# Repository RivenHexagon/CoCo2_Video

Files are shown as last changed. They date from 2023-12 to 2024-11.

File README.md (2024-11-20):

# RHCCV - Color Computer 2 S-Video and Composite Mod with Audio 

The ***RHCCV*** is a video mod for the ***Tandy Radio Shack Color Computer 2***. The modification **replaces** the **original** video **module** (the shiny metal box) of the *CoCo2*. It features a **6-pin** or **4-pin** compatible **Mini DIN** connector with **S-Video**, **Composite Video** and **Audio** outputs.

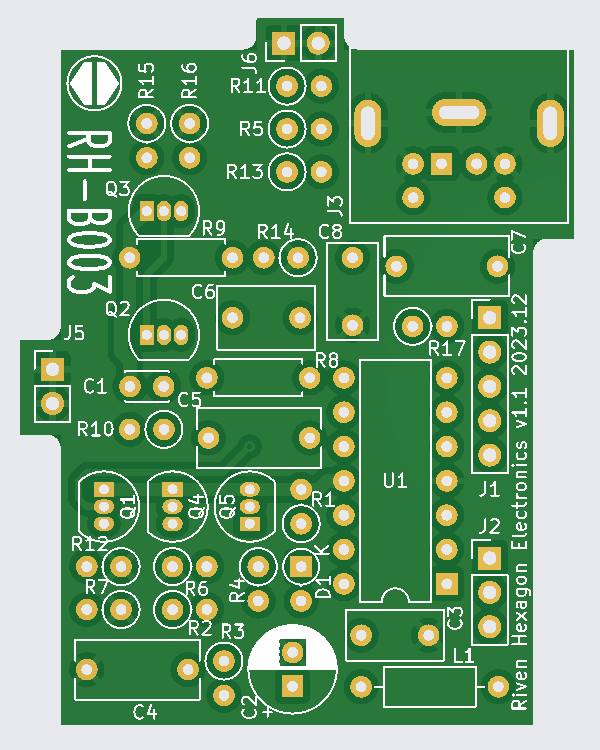
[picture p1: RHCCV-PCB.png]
MarineGEO circle logo


The [/jlcpcb](https://github.com/RivenHexagon/CoCo2_Video/tree/main/jlcpcb) folder contains production-ready files that can be directly uploaded to [jlcpcb.com](https://jlcpcb.com/) for PCB manufacturing.

## Compatibility
The current printed circuit board layout is designed to fit the CoCo2 model with a **horizontally** mounted RF **modulator** case. However, the modification itself would **also** work on earlier CoCo2 versions that use a **vertically** mounted modulator box. The only **differences** are in the **pinout** and the PCB **form factor**. I intend to develop a **revised** PCB **layout** to **fit** the **earlier** form factor, with completion expected by January 2025.
## Assembly and Installation
### 4-pin Mini DIN installed *(S-Video only)*
The **PCB** populated with a **4-pin** Mini DIN connector delivers **S-Video** as the **only** available **output**. The **pinout** is **standard** S-Video, as described [here](https://en.wikipedia.org/wiki/S-Video "S-Video Wikipedia").

### 6-Pin Mini DIN installed *(S-Video, Composite and Audio)*
The **6-pin** connector installed on the **PCB** makes **all** outputs available **simultaneously**. However, this requires a **custom** made **breakout cable** in order to **access** the **signals** individually. A veteran **PS/2** cable can be **modified** but please note that in some cables **not all pins** are **connected**.

The 6-pin Mini DIN connector has the following **pinout**:
* Pin 1: **Audio** out
* Pin 2: **Composite** Video
* Pin 3: **GND**
* Pin 4: **GND**
* Pin 5: **Luma** (Y)
* Pin 6: **Chroma** (C)

The KiCad PCB design uses a custom footprint for *ASSMANN* Mini DIN Connectors:<br>
<https://www.assmann-wsw.com/uploads/datasheets/ASS_1622_CO.pdf>

### Installation
* Desolder the **clamps** of the **metal** box and the **pin headers** of the original video module from the **main board**. (It is recommended to use a **desoldering pump** and **solder wick**)
* Carefully **desolder** the ***MC1372*** from the PCB of the original video module.
* On the RHCCV **PCB**, install a 14-pin **[IC socket](https://www.assmann-wsw.com/uploads/datasheets/ASS_0810_CO.pdf)** for **U1**, rather than soldering the ***MC1372*** directly onto the board.
* Make sure that the **pins** of the *MC1372* are **free of solder** and plug it into the **IC socket** of the RHCCV. Mind the correct **orientation**.
* Populate the remaining components listed in the [Bill of Materials](https://github.com/RivenHexagon/CoCo2_Video/blob/main/TRS-80-VideoMod-BOM.pdf).

The new PCB uses the **same** pin headers as the **original** module and does not require any additional wires to be pulled.

## The Mod
The **design** draws **inspiration** from the research and work of ***[AC's 8-bit Zone](https://youtu.be/tayGsz7Xs3A "ACs 8-bit Zone - YouTube")*** on *YouTube*. The RHCCV mod **integrates** his **S-Video** and **Conmposite Video** circuits into a **single** PCB.

The use of **Mini DIN** connectors in this PCB design provides several **benefits**:
* **Preserves** the **original hardware** (except for desoldering the *MC1372*)
* **Eliminates loose cables** exiting the TRS-80 case
* **No case modification** for extra connectors required

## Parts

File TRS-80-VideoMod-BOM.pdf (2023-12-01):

CoCo2VideoMod

Page 1

Item | Qty Reference(s) Value | LibPart | Footprint
1 | 1 C1 | 100p | Device:C | Capacitor_THT:C_Disc_D3.0mm_W2.0mm_P2.50mm
2 | 1 C2 | 220u | Device:C_Polarized | Capacitor_THT:CP_Radial_D6.3mm_P2.50mm
3 | 2 C3, C8 | 22n | Device:C | Capacitor_THT:C_Rect_L7.0mm_W3.5mm_P5.00mm
4 | 3 C4, C5, C7 | 100n | Device:C | Capacitor_THT:C_Rect_L9.0mm_W4.2mm_P7.50mm_MKT
5 | 1 C6 | 1u | Device:C | Capacitor_THT:C_Rect_L7.0mm_W4.5mm_P5.00mm
6 | 1 D1 | 1N4148 | Device:D | Diode_THT:D_DO-35_SOD27_P2.54mm_Vertical_AnodeUp
7 | 1 J1 | 20261043 Connector_Generic:Conn_01x05 Connector_PinHeader_2.54mm:PinHeader_1x05_P2.54mm_Vertical
8 | 1 J2 | to PCB | Connector_Generic:Conn_01x03 Connector_PinHeader_2.54mm:PinHeader_1x03_P2.54mm_Vertical
9 | 1 J3 | Video | Connector_Generic:Conn_01x07 Custom_Footprints:Connector_Mini-DIN_Female_6Pin_2rows
10 | 1 L1 | 10u | Device:L | Inductor_THT:L_Axial_L6.6mm_D2.7mm_P10.16mm_Horizontal_Vishay_IM-2
11 | 3 Q1, Q3, Q5 | BC547 | Transistor_BJT:BC547 | Package_TO_SOT_THT:TO-92_Inline
12 | 2 Q2, Q4 | BC557 | Transistor_BJT:BC557 | Package_TO_SOT_THT:TO-92_Inline
13 | 2 R1, R15 | 680R | Device:R | Resistor_THT:R_Axial_DIN0207_L6.3mm_D2.5mm_P2.54mm_Vertical
14 | 1 R2 | 5k6 | Device:R | Resistor_THT:R_Axial_DIN0207_L6.3mm_D2.5mm_P2.54mm_Vertical
15 | 2 R3, R4 | 220R | Device:R | Resistor_THT:R_Axial_DIN0207_L6.3mm_D2.5mm_P2.54mm_Vertical
16 | 3 R5, R11, R13 75R | Device:R | Resistor_THT:R_Axial_DIN0207_L6.3mm_D2.5mm_P2.54mm_Vertical
17 | 1 R6 | 3k3 | Device:R | Resistor_THT:R_Axial_DIN0207_L6.3mm_D2.5mm_P2.54mm_Vertical
18 | 3 R7, R12, R16 470R | Device:R | Resistor_THT:R_Axial_DIN0207_L6.3mm_D2.5mm_P2.54mm_Vertical
19 | 1 R8 | 680R | Device:R | Resistor_THT:R_Axial_DIN0207_L6.3mm_D2.5mm_P7.62mm_Horizontal
20 | 1 R9 | 4k7 | Device:R | Resistor_THT:R_Axial_DIN0207_L6.3mm_D2.5mm_P7.62mm_Horizontal
21 | 1 R10 | 330R | Device:R | Resistor_THT:R_Axial_DIN0207_L6.3mm_D2.5mm_P2.54mm_Vertical
22 | 1 R14 | 10k | Device:R | Resistor_THT:R_Axial_DIN0207_L6.3mm_D2.5mm_P2.54mm_Vertical
23 | 1 R17 | 3k9 | Device:R | Resistor_THT:R_Axial_DIN0207_L6.3mm_D2.5mm_P2.54mm_Vertical
24 | 1 U1 | MC1372P TRS-80:MC1372P | Package_DIP:DIP-14_W7.62mm

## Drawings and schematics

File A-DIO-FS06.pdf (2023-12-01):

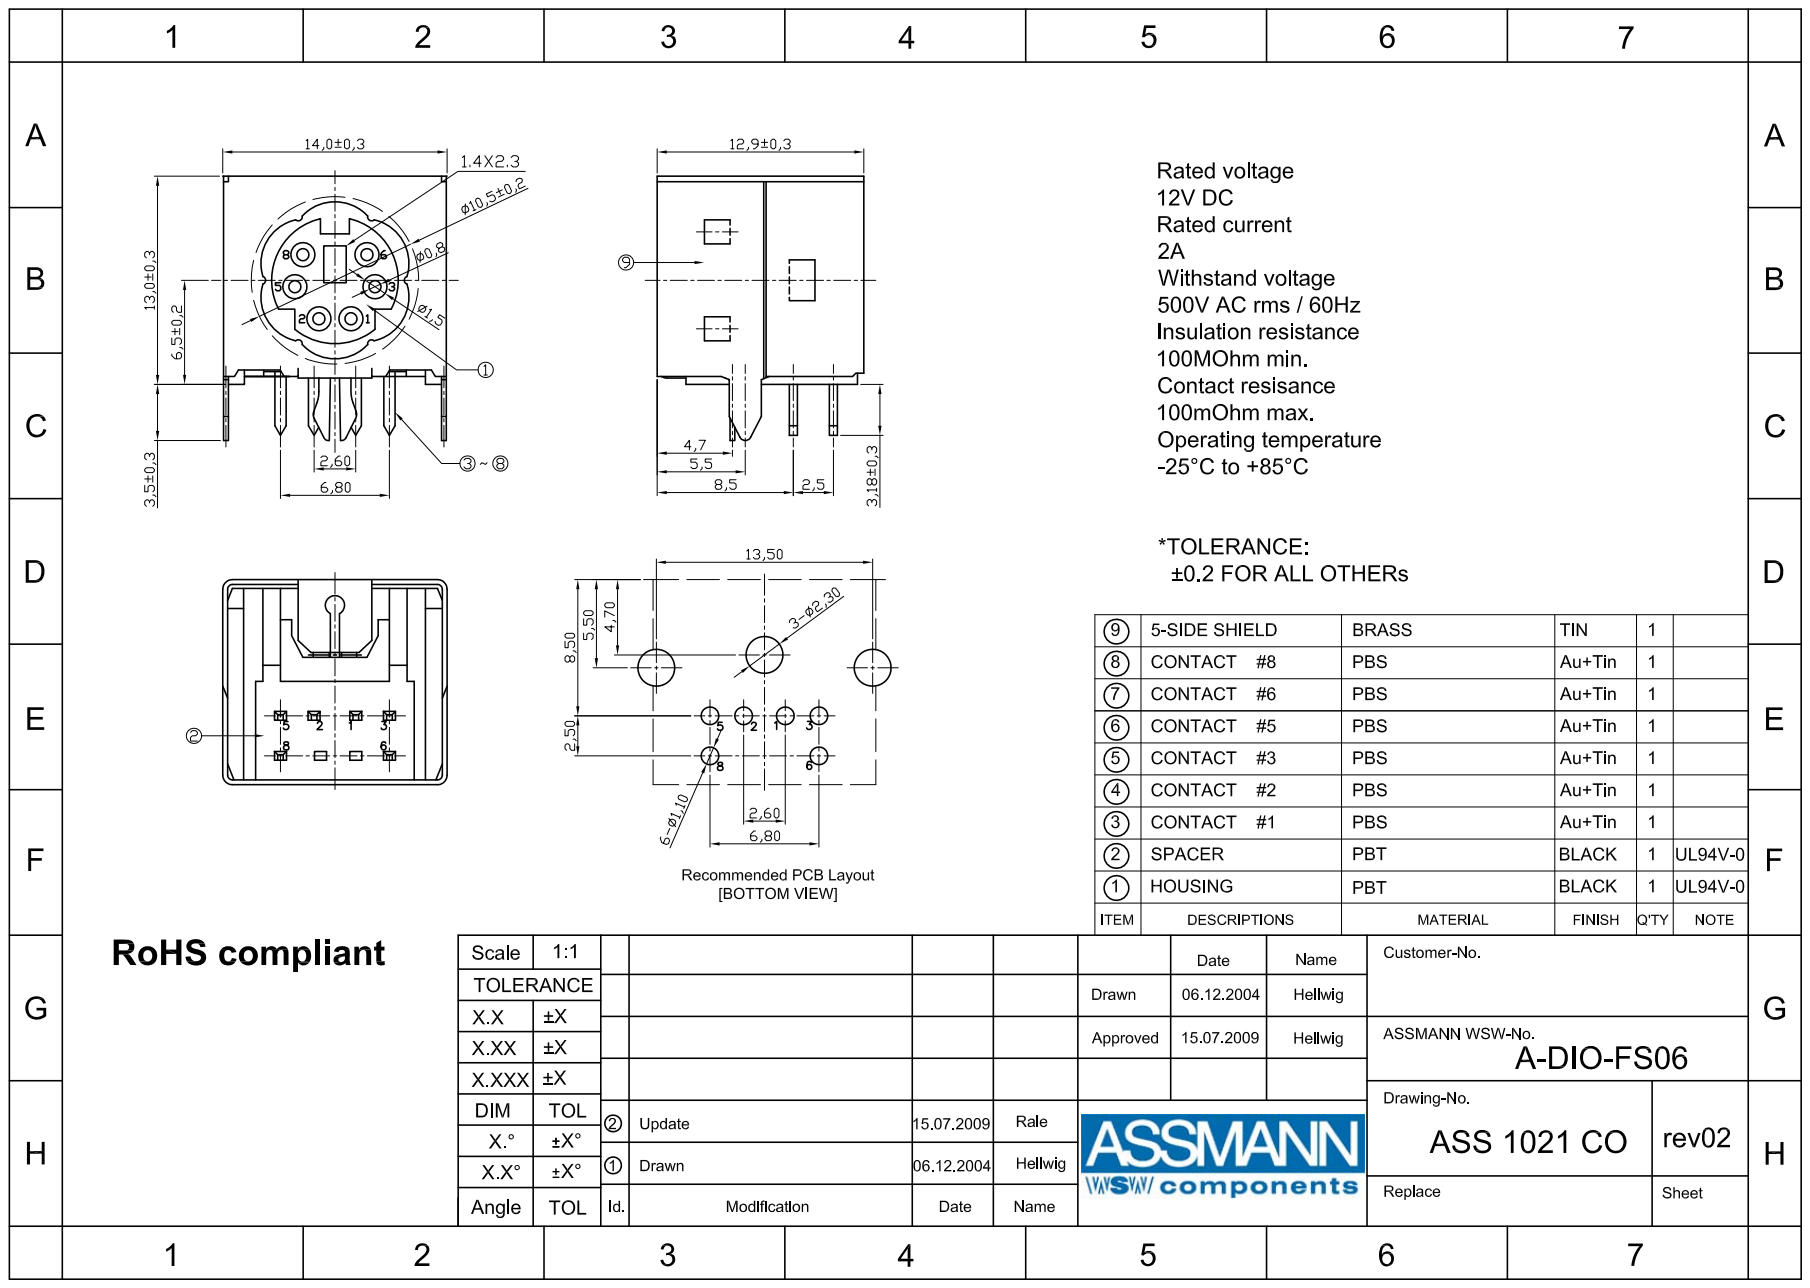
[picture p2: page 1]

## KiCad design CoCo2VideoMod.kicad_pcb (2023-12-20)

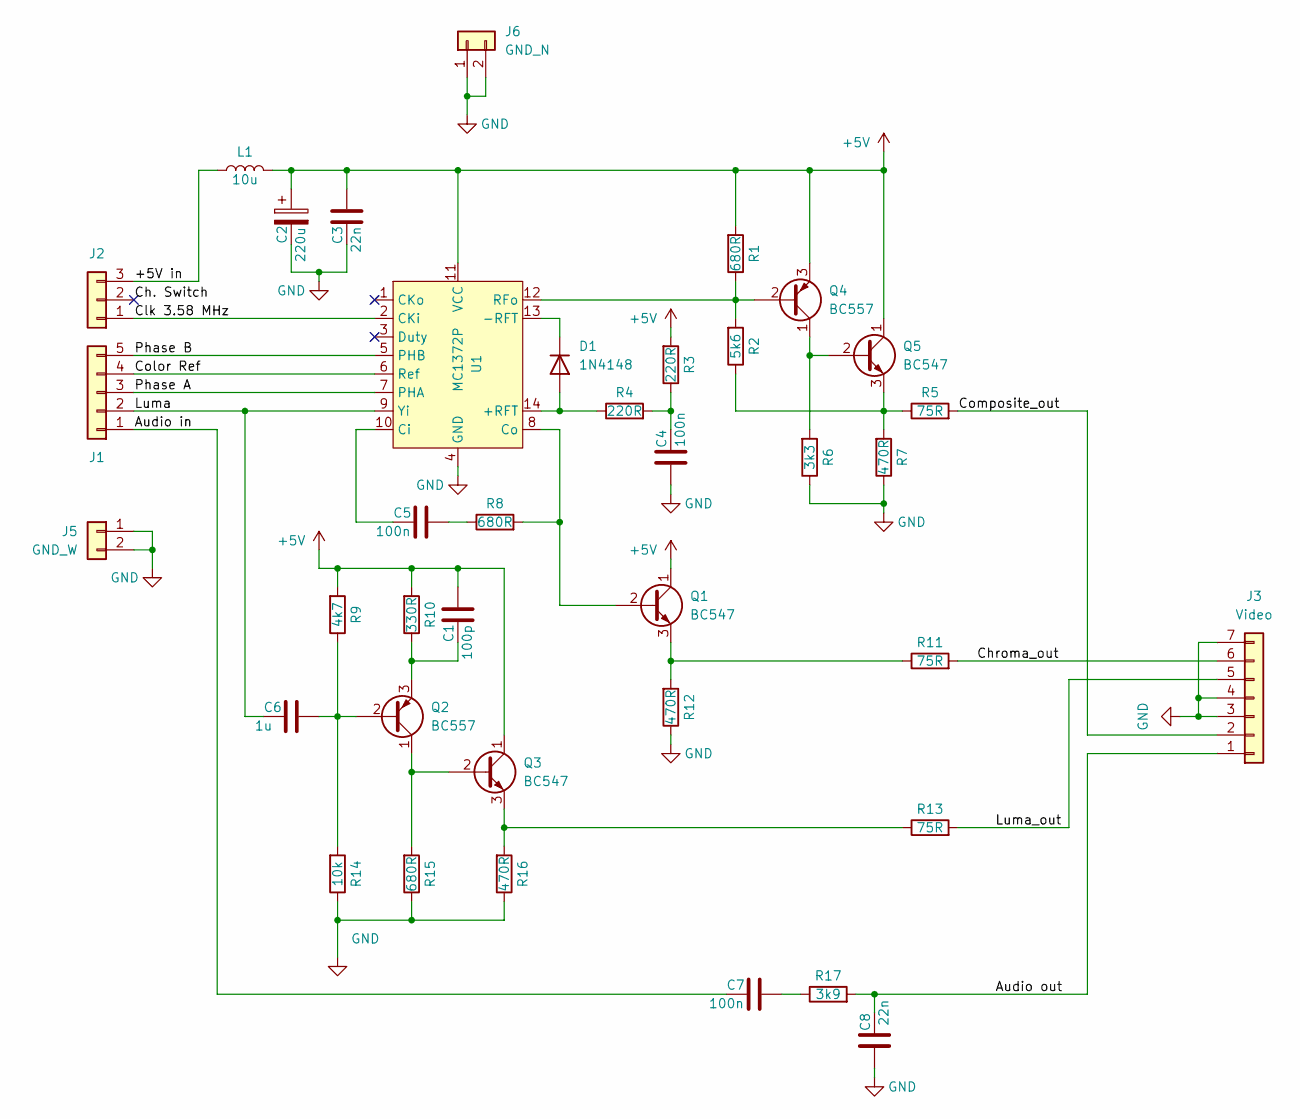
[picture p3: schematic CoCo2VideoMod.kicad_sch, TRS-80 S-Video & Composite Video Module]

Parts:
C1: 100p; C_Disc_D3.0mm_W2.0mm_P2.50mm
C2: 220u; CP_Radial_D6.3mm_P2.50mm
C3, C8: 22n; C_Rect_L7.0mm_W3.5mm_P5.00mm
C4, C5, C7: 100n; C_Rect_L9.0mm_W4.2mm_P7.50mm_MKT
C6: 1u; C_Rect_L7.0mm_W4.5mm_P5.00mm
D1: 1N4148; D_DO-35_SOD27_P2.54mm_Vertical_AnodeUp
J1: 20261043; PinHeader_1x05_P2.54mm_Vertical
J2: to PCB; PinHeader_1x03_P2.54mm_Vertical
J3: Video; Connector_Mini-DIN_Female_6Pin_2rows
J5: GND_W; PinHeader_1x02_P2.54mm_Vertical
J6: GND_N; PinHeader_1x02_P2.54mm_Vertical
L1: 10u; L_Axial_L6.6mm_D2.7mm_P10.16mm_Horizontal_Vishay_IM-2
Q1, Q3, Q5: BC547; TO-92_Inline
Q2, Q4: BC557; TO-92_Inline
R1, R15: 680R; R_Axial_DIN0207_L6.3mm_D2.5mm_P2.54mm_Vertical
R2: 5k6; R_Axial_DIN0207_L6.3mm_D2.5mm_P2.54mm_Vertical
R3, R4: 220R; R_Axial_DIN0207_L6.3mm_D2.5mm_P2.54mm_Vertical
R5, R11, R13: 75R; R_Axial_DIN0207_L6.3mm_D2.5mm_P2.54mm_Vertical
R6: 3k3; R_Axial_DIN0207_L6.3mm_D2.5mm_P2.54mm_Vertical
R7, R12, R16: 470R; R_Axial_DIN0207_L6.3mm_D2.5mm_P2.54mm_Vertical
R8: 680R; R_Axial_DIN0207_L6.3mm_D2.5mm_P7.62mm_Horizontal
R9: 4k7; R_Axial_DIN0207_L6.3mm_D2.5mm_P7.62mm_Horizontal
R10: 330R; R_Axial_DIN0207_L6.3mm_D2.5mm_P2.54mm_Vertical
R14: 10k; R_Axial_DIN0207_L6.3mm_D2.5mm_P2.54mm_Vertical
R17: 3k9; R_Axial_DIN0207_L6.3mm_D2.5mm_P2.54mm_Vertical
U1: MC1372P; DIP-14_W7.62mm

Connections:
+5V: C1.1, C2.1, C3.1, L1.2, Q1.1 (C), Q3.1 (C), Q4.3 (E), Q5.1 (C), R1.2, R3.2, R9.2, R10.2, U1.11 (VCC)
/+5V in: J2.3, L1.1
/Audio in: C7.2, J1.1
/Audio out: C8.2, J3.1, R17.2
/Ch. Switch: J2.2
/Chroma_out: J3.6, R11.2
/Clk 3.58 MHz: J2.1, U1.2 (CKi)
/Color Ref: J1.4, U1.6 (Ref)
/Composite_out: J3.2, R5.2
/Luma: C6.2, J1.2, U1.9 (Yi)
/Luma_out: J3.5, R13.2
/Phase A: J1.3, U1.7 (PHA)
/Phase B: J1.5, U1.5 (PHB)
GND: C2.2, C3.2, C4.1, C8.1, J3.3, J3.4, J3.7, J5.1, J5.2, J6.1, J6.2, R6.1, R7.1, R12.1, R14.1, R15.1, R16.1, U1.4 (GND)
unnamed: C4.2, R3.1, R4.2
unnamed: C5.1, R8.1
unnamed: C7.1, R17.1
unnamed: D1.2 (A), R4.1, U1.14 (+RFT)
unnamed: D1.1 (K), U1.13 (-RFT)
unnamed: Q1.2 (B), R8.2, U1.8 (Co)
unnamed: Q1.3 (E), R11.1, R12.2
unnamed: C6.1, Q2.2 (B), R9.1, R14.2
unnamed: Q2.1 (C), Q3.2 (B), R15.2
unnamed: C1.2, Q2.3 (E), R10.1
unnamed: Q3.3 (E), R13.1, R16.2
unnamed: Q4.2 (B), R1.1, R2.2, U1.12 (RFo)
unnamed: Q4.1 (C), Q5.2 (B), R6.2
unnamed: Q5.3 (E), R2.1, R5.1, R7.2
unnamed: C5.2, U1.10 (Ci)

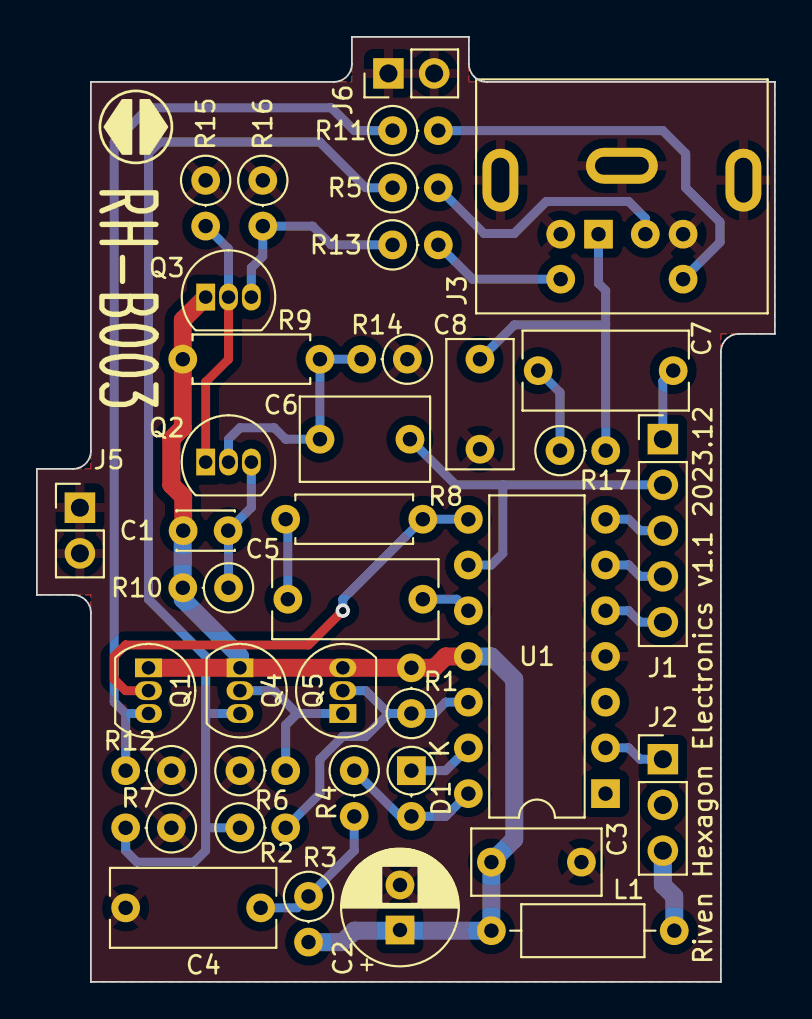
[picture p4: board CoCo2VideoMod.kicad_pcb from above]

Board: 2 copper layers, 41.0 x 52.5 mm, 38 parts (0 on the bottom side), 28 nets.

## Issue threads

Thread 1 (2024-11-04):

Variant for early (vertical) rf modulator north american coco2s?

alitel, 2024-11-04:
Hi there! This is more a question than an issue -- is this project intended specifically for the later variants of the coco2 with the horizontally mounted RF modulator can? I have an earlier (vertical rf can) coco2 version, and was hoping to add composite and/or s-video. I very much like your consolidation of the work started by ACs 8 bit zone. I'm unsure if this pcb will work in my situation though?
Many thanks! A

RivenHexagon, 2024-11-06:
Hey Alitel, the current printed circuit board layout is designed to fit the CoCo2 model with a horizontally mounted RF modulator case. However, the modification itself would also work on earlier CoCo2 versions that use the vertically mounted modulator box. The only differences are in the pinout and the PCB form factor.

The lines entering the vertical modulator box connect in the same way to the internal circuitry (primarily the MC1372) as they do in the horizontal version. You could use my PCB with the older board by adapting the pin assignments using jumper wires. A.C. provided a thorough reverse of the original schematics for both modulator variations. And I'd be happy to assist.

But your question actually inspired me to develop a layout specifically for CoCo2 models with horizontally mounted RF boxes, which I aim to complete by the end of the year. Unfortunately, I don’t have a CoCo2 with a horizontal RF box on hand, so I'll need to work out the dimensions somehow.
Best Riven

alitel, 2024-11-06:
Hi Riven -- that's great news! I just today finished connecting my coco up to an rgb2hdmi which works a treat for clarity BUT I would still like to make use of your mod when you get it built so I can select "softer" outputs for games etc. (Plus, the mod looks very fun). Let me know if I can help out -- I can take my rf can off the board and pull it apart and provide dimensions and layout pics etc. if you like.
Cheers! A

RivenHexagon, 2024-11-17:
Perfect, I think the best would be to contact me on Discord (Riven Hexagon). I"ve checked out some pictures of your CoCo Model and figured the dimensions needed. I'd send you a drawing that indicates where to take them. Looking forward!

Closed 2024-11-17.

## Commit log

2023-09-18 circuit diagramm without s-video
    [CoCo2VideoMod.kicad_pcb, CoCo2VideoMod.kicad_sch]
2023-09-18 added local symbol library
    [CoCo2VideoMod.kicad_sch]
2023-09-19 circuit diagramm completed
    [CoCo2VideoMod.kicad_sch]
2023-09-19 footprint annotation
    [CoCo2VideoMod.kicad_sch]
2023-09-19 mid routing
    [CoCo2VideoMod.kicad_pcb, CoCo2VideoMod.kicad_sch]
2023-09-19 croma and composite routing done
    [CoCo2VideoMod.kicad_pcb]
2023-09-19 midway chroma routing
    [CoCo2VideoMod.kicad_pcb, CoCo2VideoMod.kicad_sch]
2023-10-03 on luma layout
    [CoCo2VideoMod.kicad_pcb]
2023-10-03 Layout complete
    [CoCo2VideoMod.kicad_pcb, CoCo2VideoMod.kicad_sch]
2023-10-03 silk screen complete
    [CoCo2VideoMod.kicad_pcb]
2023-10-05 fab complete
    [CoCo2VideoMod.kicad_pcb, CoCo2VideoMod.kicad_sch]
2023-10-05 minor adjustments
    [CoCo2VideoMod.kicad_pcb]
2023-10-05 increased distance components to PCB edge
    [CoCo2VideoMod.kicad_pcb]
2023-12-01 production files JLC, production complete
    [BOM-CoCo2VideoMod.csv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]
2023-12-01 created BOM
    [CoCo2VideoMod.csv, CoCo2VideoMod.kicad_sch]
2023-12-16 rotated connector, added GND pins
    [CoCo2VideoMod.kicad_pcb, CoCo2VideoMod.kicad_sch]
2023-12-16 deleted faulty production files
    [BOM-CoCo2VideoMod.csv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]
2023-12-16 adjusted GND pin position, added PCB description to silk screen, started README
    [CoCo2VideoMod.kicad_pcb, CoCo2VideoMod.kicad_sch]
2023-12-20 added JLCPCB production files
    [CPL-CoCo2VideoMod.csv, CoCo2VideoMod-CuBottom.gbr, CoCo2VideoMod-CuTop.gbr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]
